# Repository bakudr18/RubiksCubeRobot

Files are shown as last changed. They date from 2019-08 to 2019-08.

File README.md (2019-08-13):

# RubiksCubeRobot

## Demo
(https://www.youtube.com/watch?v=XAhuqio9FTo&feature=youtu.be "YouTube Link")
## Introduction
Rubik's Cube Robot can solve the rubik's cube around 90 seconds including detecting and solving. This project is made by 86duino, Maixduino, OV2640 camera, RS-1270 servo motors and ws2812 led strip. The mechanisms refer to [OTVINTA](http://www.rcr3d.com/intro.html) and all of them are 3d printable. The solving algorithm was implemented by [Muodov](https://github.com/muodov/kociemba). He also made a great cube solving machine [Meccano Rubik's Shrine](http://blog.zok.pw/hacking/2016/08/12/meccano-rubiks-shrine/).

You can find more detail [here](http://www.86duino.com/?p=19296&lang=TW) in Chinese.

## Installation
Follow [86duino](http://www.86duino.com/?page_id=2844) and [Maixpy](https://maixpy.sipeed.com/en/) website to set the environment. Upload the main.ino and colorclassification.py into 86Duino and Maixduino respectively.

## Limits
* OV2640 camera's maximum exposure time is 120190us. That's why we added the led strip.
* It's important to fix the lighting environment when detecting colors, so we added the cover on top of the camera. However, we should still avoid direct illumination of the lens.
* Color classification algorithm classifies color white first because white and black are in different dimension of color space than others. Therefore, rubik's cube must have the white color.

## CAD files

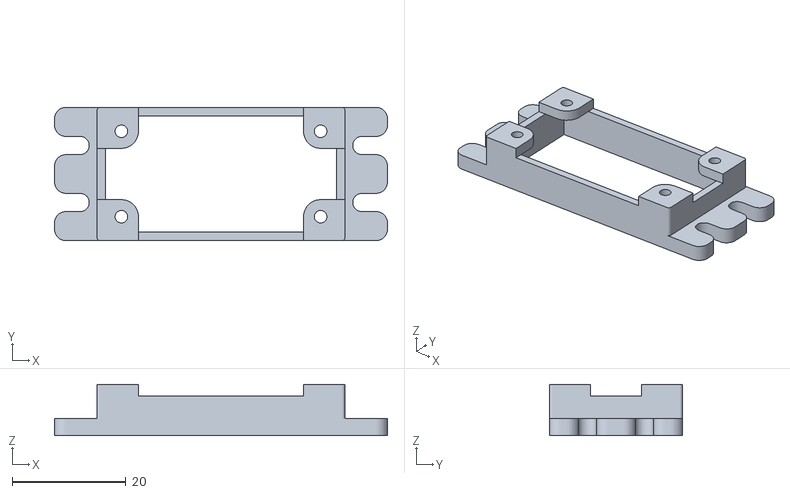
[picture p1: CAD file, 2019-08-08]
STL/servo_fixed1.STL
58.5 x 23.4 x 9.00

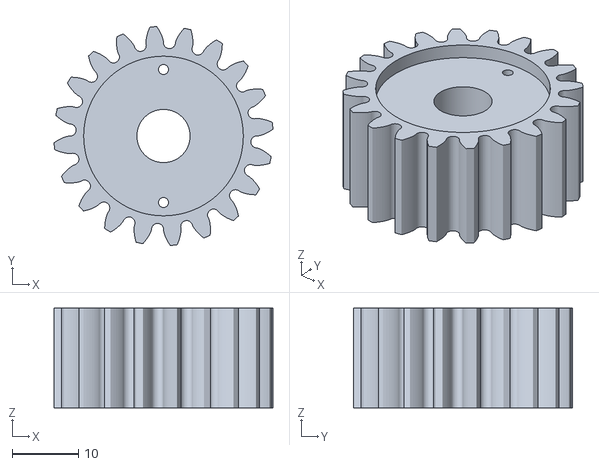
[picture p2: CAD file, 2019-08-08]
STL/rcr_pinion.stl
32.9 x 32.9 x 15.0

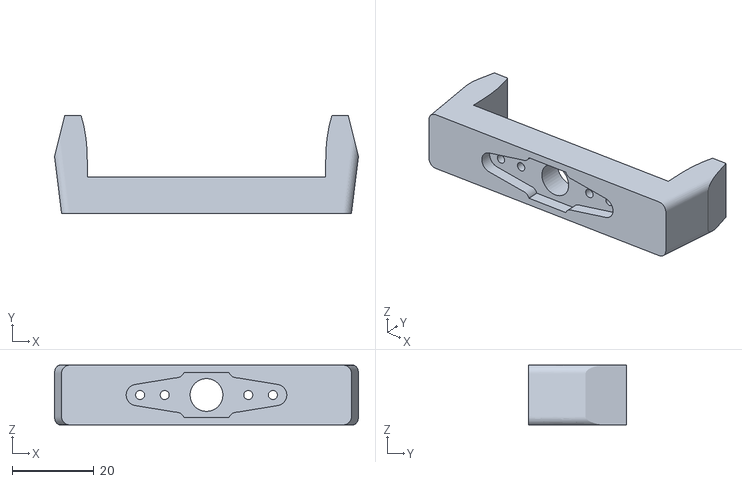
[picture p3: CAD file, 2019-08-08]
STL/clamp.STL
74.2 x 24.0 x 14.6

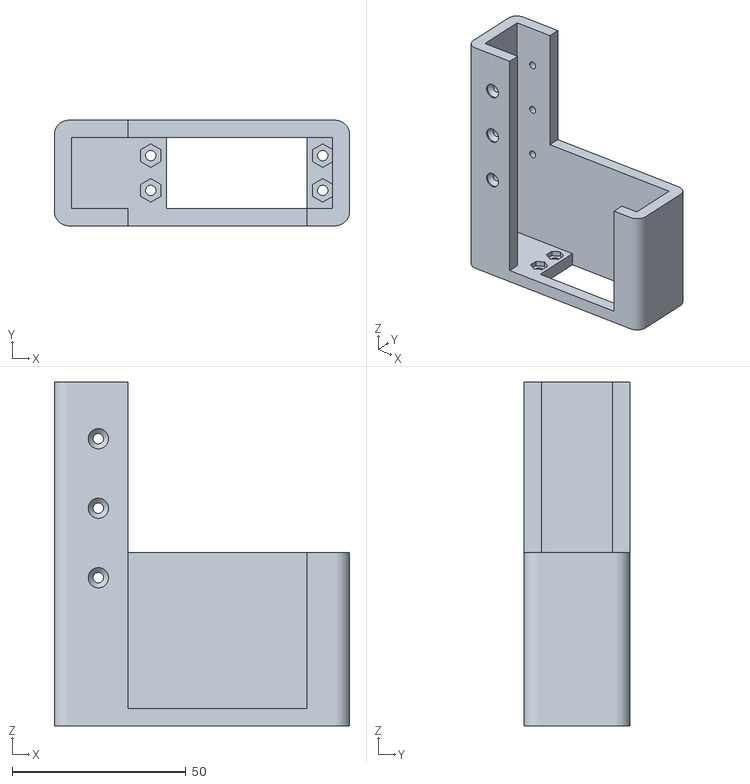
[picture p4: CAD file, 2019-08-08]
STL/rcr_slider.stl
85.0 x 30.4 x 99.0

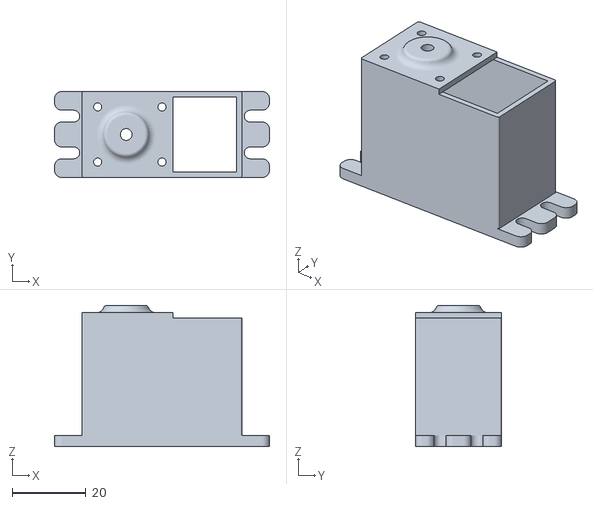
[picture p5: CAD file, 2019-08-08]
STL/servo_fixed2.STL
58.5 x 23.4 x 38.5

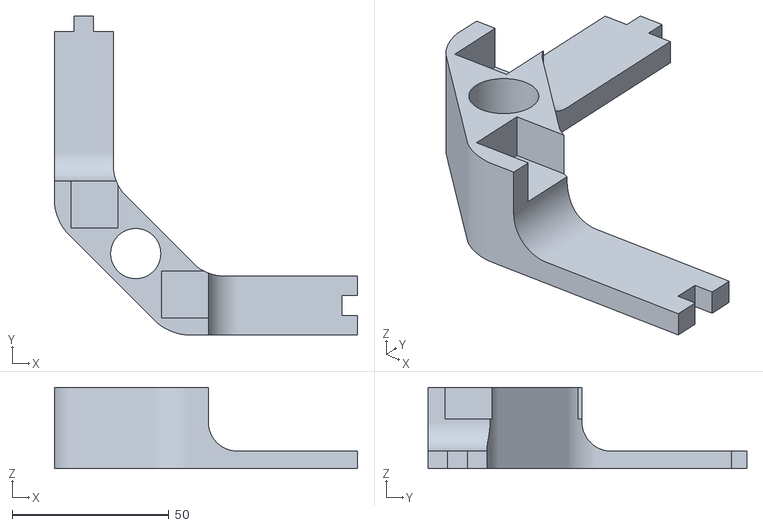
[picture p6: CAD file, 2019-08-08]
STL/rcr_corner.stl
96.9 x 101.9 x 26.0

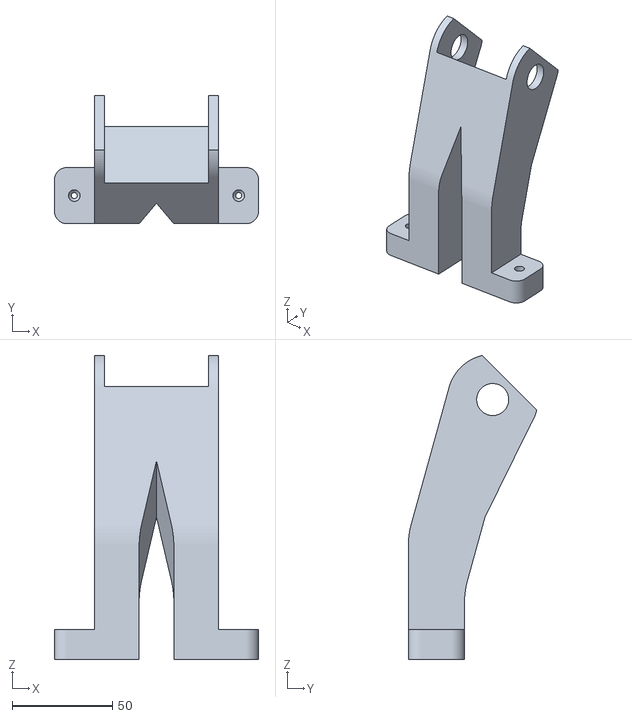
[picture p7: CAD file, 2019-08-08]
STL/rcr_leg.stl
102.2 x 64.2 x 152.0

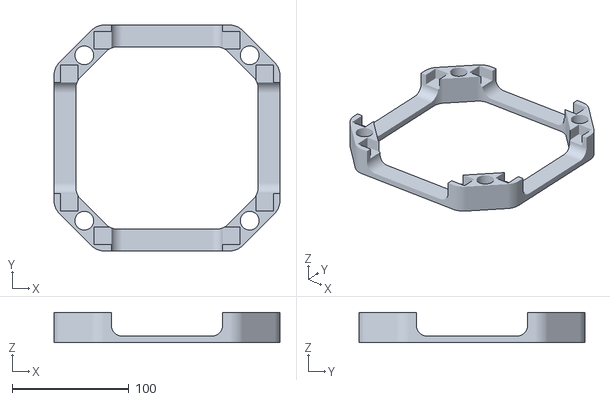
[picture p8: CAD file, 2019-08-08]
STL/rcr_4corners.stl
193.8 x 193.8 x 26.0

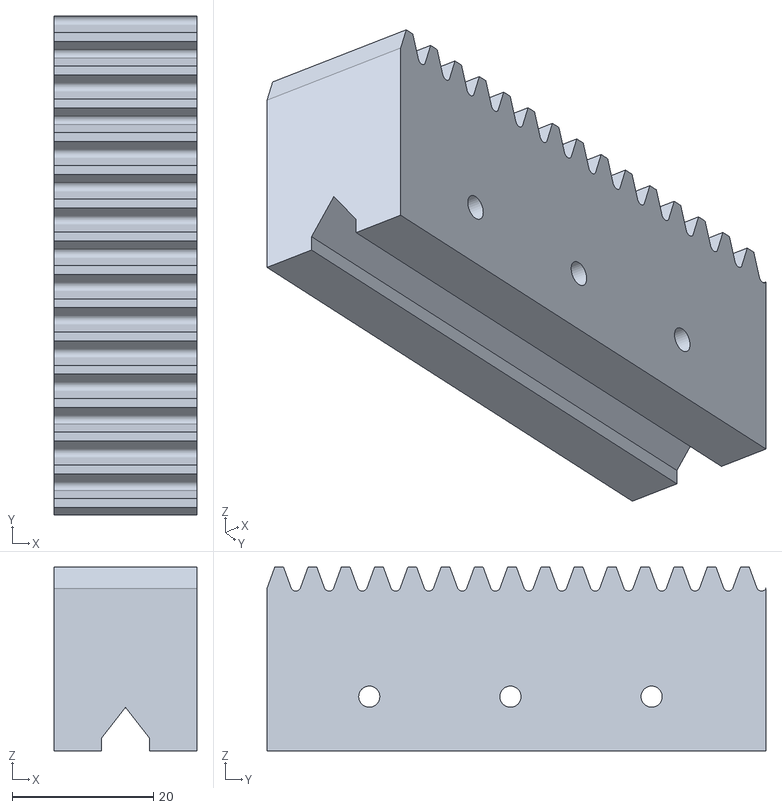
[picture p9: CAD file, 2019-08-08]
STL/rcr_rack.stl
20.2 x 70.7 x 26.0

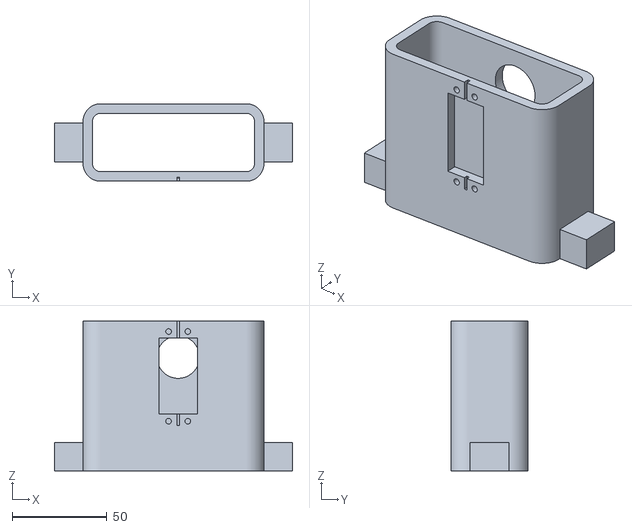
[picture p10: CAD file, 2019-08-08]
STL/rcr_arm.stl
125.4 x 40.8 x 79.0

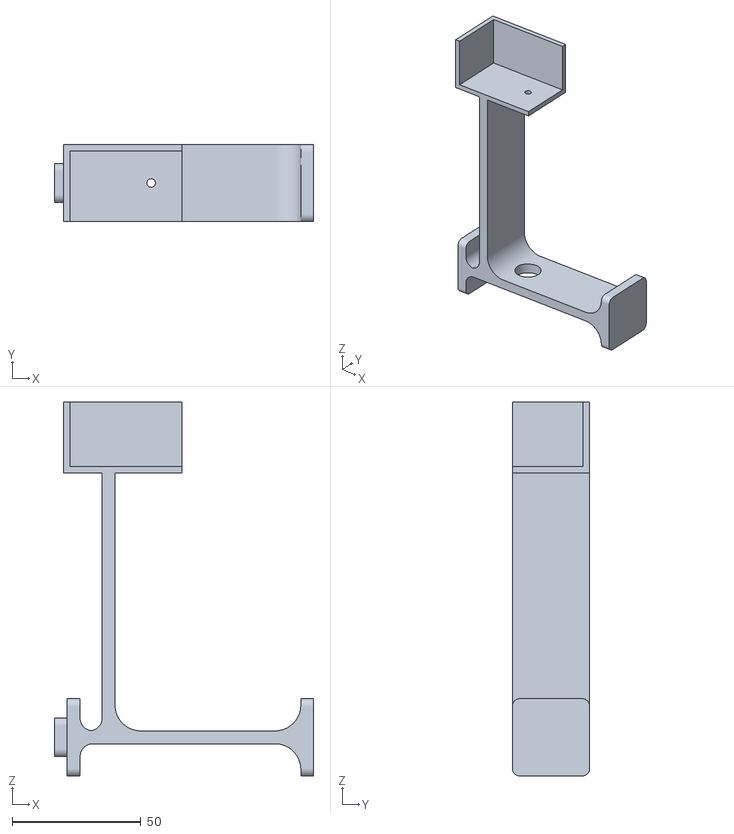
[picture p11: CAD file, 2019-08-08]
STL/plate_holder.STL
100.6 x 30.0 x 145.0

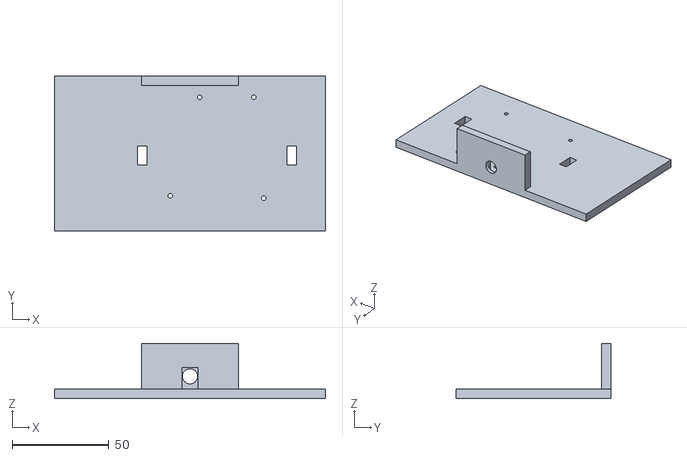
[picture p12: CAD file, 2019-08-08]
STL/plate_maixduino.STL
140.0 x 80.0 x 28.5

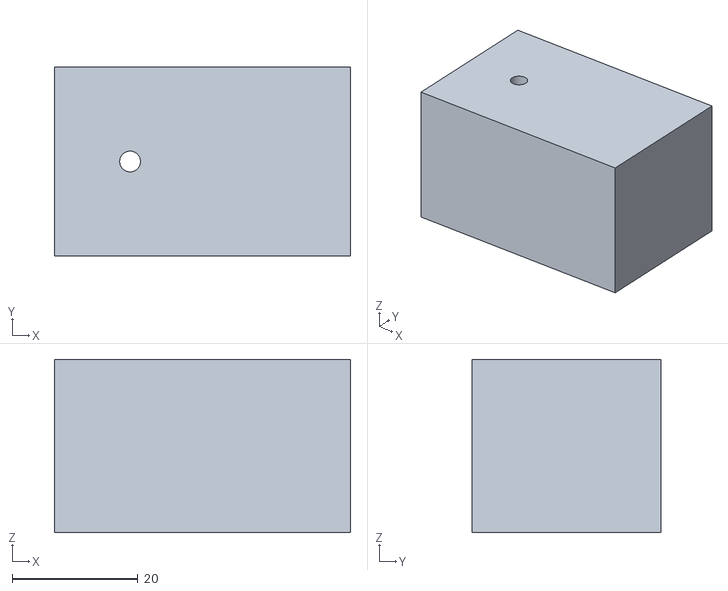
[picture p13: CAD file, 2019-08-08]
STL/cover_lock.STL
47.0 x 30.0 x 27.5

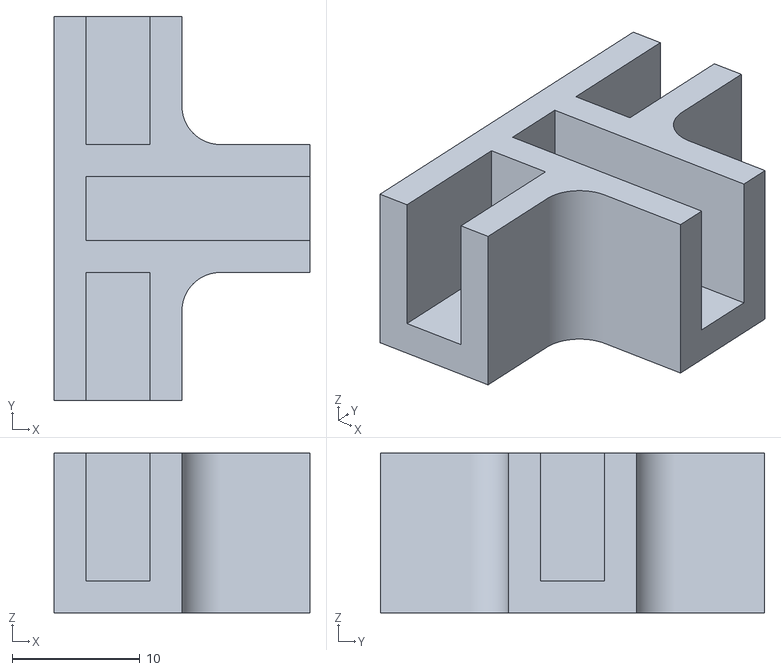
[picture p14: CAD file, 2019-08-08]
STL/joint3.STL
20.0 x 30.0 x 12.5

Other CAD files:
STL/rcr_pinion2.stl
STL/plate_86duino.STL
STL/pillar.STL
STL/cover.STL
STL/arm_left.STL
STL/arm_right.STL
STL/joint1.STL
STL/joint2.STL
STL/joint4.STL
STL/joint5.STL
STL/pillar_short.STL
STL/plate_bottom.STL
STL/rcr_long_bolt.stl
STL/rcr_nut.stl
STL/rcr_short_bolt.stl

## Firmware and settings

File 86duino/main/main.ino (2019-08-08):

#include <Servo86.h>
#include <FastLED.h> 
#include <string.h>
#include <stdio.h>

/*
 ported form 
 https://github.com/muodov/kociemba
 */
extern "C"{
  #include "search.h"
}

#define LED_PIN     5 // useless
#define NUM_LEDS    18
#define BRIGHTNESS  200
#define LIGHTOFF    0
#define LED_TYPE    WS2812
#define COLOR_ORDER GRB
CRGB leds[NUM_LEDS];
CRGBPalette16 currentPalette;
TBlendType    currentBlending;


enum { UT = 0, US = 1, RT = 2, RS = 3, LT, LS, DT, DS}; // T : turn, S : slide

Servo myservo[8];

const int DELAY_TIME = 200;
const int CLAMP_UPPER_BOUND = 2100; // rotate 90 degree
const int CLAMP_LOWER_BOUND = 1100; // initial angle 0 degree
const int SLIDE_UPPER_BOUND = 2100;
const int UD_SLIDE_LOWER_BOUND = 965;
const int RL_SLIDE_LOWER_BOUND = 760;
const int UPPER = 0;
const int LOWER = 1;
const int CURR = 2;

int bound[8][3];  // upper bound, lower bound, and current position (us) of each pin

void turning(char *s);
void turningFace(int pin1, int pin2);
void turningCube(int tpin1, int tpin2);
void fixedCube(int latch1, int latch2, bool lock);
void showCube();
void servoRun(int pin, int pos, int delay_time);
void doubleRun(int pin1, int pos1, int pin2, int pos2, int delay_time);

void setup() {
  // turn on the LED
  delay(3000);
  FastLED.addLeds<LED_TYPE, LED_PIN, COLOR_ORDER>(leds, NUM_LEDS).setCorrection( TypicalLEDStrip );
  FastLED.setBrightness(  BRIGHTNESS );
  
  currentPalette = RainbowColors_p;
  currentBlending = LINEARBLEND;

  SetupBlackAndWhiteStripedPalette();
  FillLEDsFromPaletteColors(1);
  FastLED.show();
  delay(500);
  // initialize bound tables
  int i;
  for(i = 0; i < 8; i += 2){
    bound[i][UPPER] = CLAMP_UPPER_BOUND;
    bound[i][LOWER] = CLAMP_LOWER_BOUND;
    bound[i + 1][UPPER] = SLIDE_UPPER_BOUND;
  }
  bound[US][LOWER] = bound[DS][LOWER] = UD_SLIDE_LOWER_BOUND;
  bound[RS][LOWER] = bound[LS][LOWER] = RL_SLIDE_LOWER_BOUND;
  for(i = 0; i < 8; i++)
    bound[i][CURR] = bound[i][LOWER];

  // attach the servoes 
  myservo[UT].attach(21);
  myservo[US].attach(22);
  myservo[RT].attach(23);
  myservo[RS].attach(24);
  myservo[LT].attach(25);
  myservo[LS].attach(26);
  myservo[DT].attach(27);
  myservo[DS].attach(28);

  // adjust the mid offset of servo
  myservo[UT].setOffset(-55);
  myservo[RT].setOffset(-50);
  myservo[RS].setOffset(-60);
  myservo[LS].setOffset(40);
  
  // reset to released position
  myservo[DS].setPosition(1600);
  myservo[US].setPosition(1600);
  myservo[RS].setPosition(1600);
  myservo[LS].setPosition(1600);
  servoMultiRun(myservo[DS], myservo[US], myservo[RS], myservo[LS]);
  delay(DELAY_TIME);

  // move clamps to 0 degree
  myservo[DT].setPosition(bound[DT][LOWER]);
  myservo[UT].setPosition(bound[UT][LOWER]);
  myservo[RT].setPosition(bound[RT][LOWER]);
  myservo[LT].setPosition(bound[LT][LOWER]);
  servoMultiRun(myservo[DT], myservo[UT], myservo[RT], myservo[LT]);
  delay(DELAY_TIME);

  // move cube to center position
  myservo[DS].setPosition(bound[DS][LOWER]);
  myservo[US].setPosition(bound[US][LOWER]);
  myservo[RS].setPosition(bound[RS][LOWER]);
  myservo[LS].setPosition(bound[LS][LOWER]);
  servoMultiRun(myservo[DS], myservo[US], myservo[RS], myservo[LS]);
  delay(DELAY_TIME);
  
  Serial.begin(9600);
  Serial1.begin(9600);
}

void loop() {
  char facelets[55];
  
  // wait for finding cube center and setting camera gain
  if(waitUntilFoundCenter() == 0){
    releaseCube();
    while(1);
  }

  // detect 6 faces
  showCube();

  // turn off the led
  FastLED.setBrightness(LIGHTOFF);
  FastLED.show();
  
  // wait until color classification finish
  while(Serial1.available() == 0);
  if(readFacelets(facelets) == 54){
    // sloving by Kociemba's Algorithm
    char *sol = solution(facelets,24,1000,0,"cache");
    if (sol == NULL) {
      Serial.println("Unsolvable cube!");
      releaseCube();
      while(1);
    }

    // adjust the solution because of turning cube F and B
    adjustSolFace(sol);
    Serial.println(sol);

    // split the string to turning cube
    char *pch;
    pch = strtok (sol," ");
    while (pch != NULL)
    {
      Serial.println(pch);
      turning(pch);
      pch = strtok (NULL, " ");
    }
    free(sol);
  }

  // release cube
  releaseCube();
  while(1);
}

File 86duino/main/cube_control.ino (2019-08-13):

void chr_replace(char *orig, char *rep, char *with){
  char *s;
  char *pr, *pw;
  if(strlen(rep) != strlen(with))
    return;
  
  for(s = orig; *s != '\0'; s++)
    for(pr = rep, pw = with; *pr != '\0'; pr++, pw++)
      if(*s == *pr){
        *s = *pw;
        break;
      }
}

void adjustSolFace(char *sol){
  char *s;
  for(s = sol; *s != '\0'; s++){
    if(*s == 'F')
      chr_replace(s + 1, "FBUD", "UDBF");
    else if(*s == 'B')
      chr_replace(s + 1, "BFUD", "UDFB");
  }
}

void turning(char *s){
  int i;
  if(strcmp(s, "U") == 0)
    turningFace(UT, US); 
  else if(strcmp(s, "U\'") == 0)
    turningFace(US, UT);
  else if(strcmp(s, "U2") == 0)
    for(i = 0; i < 2; i++)
      turningFace(UT, US);
  else if(strcmp(s, "D") == 0)
    turningFace(DT, DS);
  else if(strcmp(s, "D\'") == 0)
    turningFace(DS, DT);
  else if(strcmp(s, "D2") == 0)
    for(i = 0; i < 2; i++)
      turningFace(DT, DS);
  else if(strcmp(s, "R") == 0)
    turningFace(RT, RS);
  else if(strcmp(s, "R\'") == 0)
    turningFace(RS, RT);
  else if(strcmp(s, "R2") == 0)
    for(i = 0; i < 2; i++)
      turningFace(RT, RS);
  else if(strcmp(s, "L") == 0)
    turningFace(LT, LS);
  else if(strcmp(s, "L\'") == 0)
    turningFace(LS, LT);
  else if(strcmp(s, "L2") == 0)
    for(i = 0; i < 2; i++)
      turningFace(LT, LS);
  else if(strcmp(s, "X") == 0)
    turningCube(LT, RT);
  else if(strcmp(s, "X\'") == 0)
    turningCube(RT, LT);
  else if(strcmp(s, "X2") == 0)
    for(i = 0; i < 2; i++)
      turningCube(LT, RT);
  else if(strcmp(s, "Y") == 0)
    turningCube(DT, UT);
  else if(strcmp(s, "Y\'") == 0)
    turningCube(UT, DT);
  else if(strcmp(s, "Y2") == 0)
    for(i = 0; i < 2; i++)
      turningCube(UT, DT);
  else if(strcmp(s, "F") == 0){
    turning("X");
    turning("U");
  }
  else if(strcmp(s, "F\'") == 0){
    turning("X");
    turning("U\'");
  }
  else if(strcmp(s, "F2") == 0){
    turning("X");
    for(i = 0; i < 2; i++)
      turning("U");
  }
   else if(strcmp(s, "B") == 0){
    turning("X\'");
    turning("U");
  }
  else if(strcmp(s, "B\'") == 0){
    turning("X\'");
    turning("U\'");
  }
  else if(strcmp(s, "B2") == 0){
    turning("X\'");
    for(i = 0; i < 2; i++)
      turning("U");
  }
}

void turningFace(int pin1, int pin2){
  if( pin1 >= 8 || pin1 < 0 || pin2 >= 8 || pin2 < 0)
    return;
  int latch1, latch2;
  if( pin1 == US || pin1 == UT || pin1 == DS || pin1 == DT){
    latch1 = RT;
    latch2 = LT;
  }
  else{
    latch1 = UT;
    latch2 = DT;
  }
  fixedCube(latch1, latch2, true);
  servoRun(pin1, bound[pin1][UPPER], DELAY_TIME);
  servoRun(pin2, bound[pin2][UPPER], DELAY_TIME);
  servoRun(pin1, bound[pin1][LOWER], DELAY_TIME);
  servoRun(pin2, bound[pin2][LOWER], DELAY_TIME);
  fixedCube(latch1, latch2, false);
}

void turningCube(int tpin1, int tpin2){
  if( tpin1 >= 8 || tpin1 < 0 || tpin2 >= 8 || tpin2 < 0 || tpin1 % 2 != 0 || tpin2 % 2 != 0) // check turning pin
    return;
  int tlatch1, tlatch2, slatch1, slatch2, spin1, spin2;
  if(tpin1 == UT || tpin1 == DT){
    tlatch1 = RT;
    tlatch2 = LT;
  }
  else{
    tlatch1 = UT;
    tlatch2 = DT;
  }
  spin1 = tpin1 + 1;
  spin2 = tpin2 + 1;
  slatch1 = tlatch1 + 1;
  slatch2 = tlatch2 + 1;
  
  fixedCube(tlatch1, tlatch2, true);
  servoRun(spin1, bound[spin1][UPPER], DELAY_TIME);
  servoRun(tpin1, bound[tpin1][UPPER], DELAY_TIME);
  servoRun(spin1, bound[spin1][LOWER], DELAY_TIME);
  fixedCube(tlatch1, tlatch2, false);
  doubleRun(slatch1, bound[slatch1][UPPER], slatch2, bound[slatch2][UPPER], DELAY_TIME);

  doubleRun(tpin1, bound[tpin1][LOWER], tpin2, bound[tpin2][UPPER], DELAY_TIME);

  doubleRun(slatch1, bound[slatch1][LOWER], slatch2, bound[slatch2][LOWER], DELAY_TIME);
  fixedCube(tlatch1, tlatch2, true);
  servoRun(spin2, bound[spin2][UPPER], DELAY_TIME);
  servoRun(tpin2, bound[tpin2][LOWER], DELAY_TIME);
  servoRun(spin2, bound[spin2][LOWER], DELAY_TIME);
  fixedCube(tlatch1, tlatch2, false);
}

void fixedCube(int latch1, int latch2, bool lock){
  // fix the cube by the rest of clamps to avoid sliding
  if(lock == true)
    doubleRun(latch1, bound[latch1][LOWER] + 50, latch2, bound[latch2][LOWER] + 50, 30);
  else
    doubleRun(latch1, bound[latch1][LOWER], latch2, bound[latch2][LOWER], 30);
}

void showFace(int tpin1, int tpin2){
  // turn the clamps to 90 degree to show the face of cube
  if( tpin1 >= 8 || tpin1 < 0 || tpin2 >= 8 || tpin2 < 0 || tpin1 % 2 != 0 || tpin2 % 2 != 0) // check turning pin
    return;
  int tlatch1, tlatch2, slatch1, slatch2, spin1, spin2;
  if(tpin1 == UT || tpin1 == DT){
    tlatch1 = RT;
    tlatch2 = LT;
  }
  else{
    tlatch1 = UT;
    tlatch2 = DT;
  }
  spin1 = tpin1 + 1;
  spin2 = tpin2 + 1;
  slatch1 = tlatch1 + 1;
  slatch2 = tlatch2 + 1;
  
  fixedCube(tlatch1, tlatch2, true);
  doubleRun(spin1, bound[spin1][UPPER], spin2, bound[spin2][UPPER], DELAY_TIME);
  doubleRun(tpin1, bound[tpin1][UPPER], tpin2, bound[tpin2][UPPER], DELAY_TIME);
  doubleRun(spin1, bound[spin1][LOWER], spin2, bound[spin2][LOWER], DELAY_TIME);
  fixedCube(tlatch1, tlatch2, false);
  //doubleRun(slatch1, bound[slatch1][UPPER], slatch2, bound[slatch2][UPPER], DELAY_TIME);
  doubleRun(slatch1, bound[slatch1][LOWER] + 500, slatch2, bound[slatch2][LOWER] + 500, DELAY_TIME);
  waitUntilSnapshot();  // snapshot
  doubleRun(slatch1, bound[slatch1][LOWER], slatch2, bound[slatch2][LOWER], DELAY_TIME);

}
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

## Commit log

2019-08-08 1st edition
    [arm_left.STL, arm_right.STL, cover.STL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]
2019-08-08 robot STL files
    [clamp.STL, rcr_4corners.stl, rcr_arm.stl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]
2019-08-13 showFace() slatch upper fixed
    [cube_control.ino]
